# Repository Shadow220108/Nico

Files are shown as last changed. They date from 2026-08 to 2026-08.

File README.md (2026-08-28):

<h1 align="center">
  <br>
  Screenshot 2026-08-28 032631-Photoroom

  <br>
  Nico
  <br>
</h1>
<h3 align="center">
Ultra-compact USB dongle with a 56-LED Charlieplexed visualizer and native CH552 8051 control.
</h3>

| Spinnyy |
| --- |
|  |

| Front Render | Back Render | 
| --- | --- |
|| | 

## PCB Design 
| |
|--- |  

 ### The PCB is 2 layers with dimensions 76 by 21 mm

## Schematics  

Here are the schematic designs,

| |
| --- |  

## How can you get one for yourself? 

That is pretty easy, you have all the files you will need in the production folder, order the development  
board from any PCB fab ( I chose JLC cause its cheap and has good quality ) and BINGO! You will have it  
to use for any purpose you want!  

## BOM  
|Name|Purpose |Quantity|Total Cost (USD)|Link |Distributor|
|----|---|---|---|---|---|
|PCB |Development Board|5 |43.09 ( After coupons ) |https://jlcpcb.com/|JLCPCB |
|Components |all the components grouped together|1 | 28.75 |https://www.lcsc.com|LCSC |
| | | Total | 71.84 | 

LCSC BOM for the components on board is [here](https://github.com/Shadow220108/Nico/blob/main/production/bom.csv)

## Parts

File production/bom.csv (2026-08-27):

Designator | Footprint | Quantity | Value | LCSC Part #
220R, R3, R4, R5, R6, R7, R8, R9 | 0603 | 8 | 220R
BOOT | SW_SPST_TS-1088-xR020 | 1 | Boot
C1, C2 | 0603 | 2 | 100nF
D1, D10, D11, D12, D13, D14, D15, D16, D17, D18, D19, D2, D20, D21, D22, D23, D24, D25, D26, D27, D28, D29, D3, D30, D31, D32, D33, D34, D35, D36, D37, D38, D39, D4, D40, D41, D42, D43, D44, D45, D46, D47, D48, D49, D5, D50, D51, D52, D53, D54, D55, D56, D6, D7, D8, D9 | 0603 | 56 | RED
J1 | USB-A | 1 | USB_A
R1 | 0603 | 1 | 10k
U1 | SOIC-16_3.9x9.9mm_P1.27mm | 1 | CH552G | C111292

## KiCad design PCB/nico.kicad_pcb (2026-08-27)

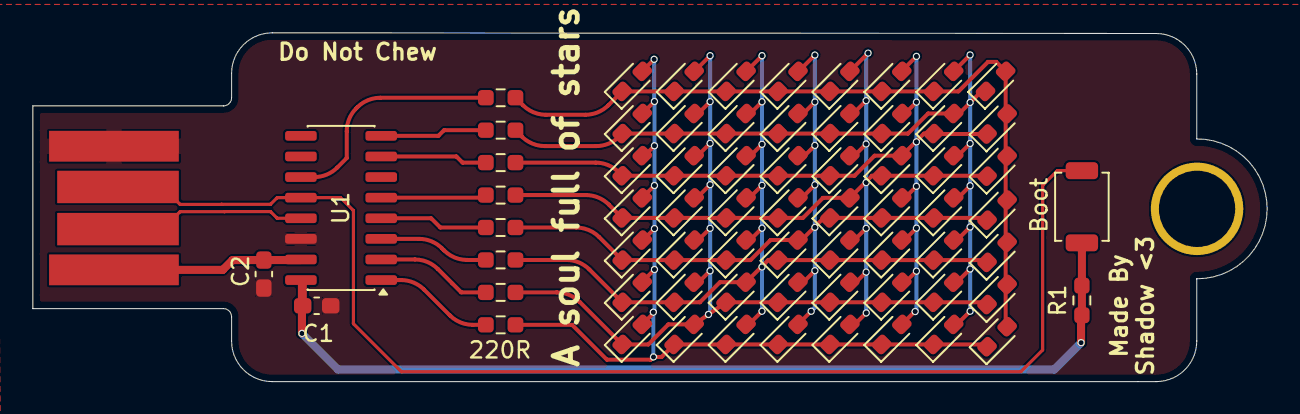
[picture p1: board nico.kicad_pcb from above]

Board: 2 copper layers, 76.1 x 21.5 mm, 70 parts (0 on the bottom side), 14 nets.

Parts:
220R: 220R; R_0603_1608Metric_Pad0.98x0.95mm_HandSolder
Boot: Boot; SW_SPST_TS-1088-xR020
C1, C2: 100nF; C_0603_1608Metric_Pad1.08x0.95mm_HandSolder
D1, D2, D3, D4, D5, D6, D7, D8, D9, D10, D11, D12, D13, D14, D15, D16, D17, D18, D19, D20, D21, D22, D23, D24, D25, D26, D27, D28, D29, D30, D31, D32, D33, D34, D35, D36, D37, D38, D39, D40, D41, D42, D43, D44, D45, D46, D47, D48, D49, D50, D51, D52, D53, D54, D55, D56: RED; LED_0603_1608Metric_Pad1.05x0.95mm_HandSolder
J1: USB_A; USB-A
R1: 10k; R_0603_1608Metric_Pad0.98x0.95mm_HandSolder
R3, R4, R5, R6, R7, R8, R9: 220R; R_0603_1608Metric_Pad0.98x0.95mm_HandSolder
U1: CH552G; SOIC-16_3.9x9.9mm_P1.27mm

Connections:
+3V3: C1.1, R1.1, U1.16 (V33)
/D+: Boot.1, J1.3 (D+), U1.12 (P3.6/UDP)
/D-: J1.2 (D-), U1.13 (P3.7/UDM)
/ROW0: 220R.1, 220R.2, D1.1 (K), D8.1 (K), D15.1 (K), D22.1 (K), D29.1 (K), D36.1 (K), D43.1 (K), D50.2 (A), D51.2 (A), D52.2 (A), D53.2 (A), D54.2 (A), D55.2 (A), D56.2 (A), U1.11 (P3.4/PWM2/RXD1_/T0)
/ROW1: D2.1 (K), D9.1 (K), D16.1 (K), D23.1 (K), D30.1 (K), D37.1 (K), D43.2 (A), D44.2 (A), D45.2 (A), D46.2 (A), D47.2 (A), D48.2 (A), D49.2 (A), D50.1 (K), R3.1, R3.2, U1.8 (P3.0/PWM1_/RXD)
/ROW2: D3.1 (K), D10.1 (K), D17.1 (K), D24.1 (K), D31.1 (K), D36.2 (A), D37.2 (A), D38.2 (A), D39.2 (A), D40.2 (A), D41.2 (A), D42.2 (A), D44.1 (K), D51.1 (K), R4.1, R4.2, U1.7 (P3.1/PWM2_/TXD)
/ROW3: D4.1 (K), D11.1 (K), D18.1 (K), D25.1 (K), D29.2 (A), D30.2 (A), D31.2 (A), D32.2 (A), D33.2 (A), D34.2 (A), D35.2 (A), D38.1 (K), D45.1 (K), D52.1 (K), R5.1, R5.2, U1.5 (P1.7/SCK/TXD1/TIN5)
/ROW4: D5.1 (K), D12.1 (K), D19.1 (K), D22.2 (A), D23.2 (A), D24.2 (A), D25.2 (A), D26.2 (A), D27.2 (A), D28.2 (A), D32.1 (K), D39.1 (K), D46.1 (K), D53.1 (K), R6.1, R6.2, U1.4 (P1.6/MISO/RXD1/TIN4)
/ROW5: D6.1 (K), D13.1 (K), D15.2 (A), D16.2 (A), D17.2 (A), D18.2 (A), D19.2 (A), D20.2 (A), D21.2 (A), D26.1 (K), D33.1 (K), D40.1 (K), D47.1 (K), D54.1 (K), R7.1, R7.2, U1.3 (P1.5/MOSI/PWM1/TIN3/UCC2/AIN2)
/ROW6: D7.1 (K), D8.2 (A), D9.2 (A), D10.2 (A), D11.2 (A), D12.2 (A), D13.2 (A), D14.2 (A), D20.1 (K), D27.1 (K), D34.1 (K), D41.1 (K), D48.1 (K), D55.1 (K), R8.1, R8.2, U1.2 (P1.4/T2_/CAP1_/SCS/TIN2/UCC1/AIN1)
/ROW7: D1.2 (A), D2.2 (A), D3.2 (A), D4.2 (A), D5.2 (A), D6.2 (A), D7.2 (A), D14.1 (K), D21.1 (K), D28.1 (K), D35.1 (K), D42.1 (K), D49.1 (K), D56.1 (K), R9.1, R9.2, U1.1 (P3.2/TXD1_/INT0/VBUS1/AIN3)
GND: C1.2, C2.2, J1.4 (GND), U1.14 (GND/VSS)
unnamed: Boot.2, R1.2
VBUS: C2.1, J1.1 (VBUS), U1.15 (VCC/VDD)

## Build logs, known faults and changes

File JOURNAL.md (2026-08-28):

## Nico

Ultra-compact USB dongle with a 56-LED Charlieplexed visualizer and native CH552 8051 control.

## Total Hours : 14.4 hours

#### August 27, 2:33 am 
 Time Spent : 1.8 hours  
Starting with the #dongle ysws, I found this pretty cool ysws to make my own dongle! On top of it, it is run by @Sophia ( fallout was so fun cause of her ), okay so now I need an idea, after scrolling through internet and braingstorming I came up with designing an LED matrix, using the CH32V003 chip 
One of the inspo I found : 
Five Boards

After talking with @Sophia on channel I found out that I should switch to a chip that supports native USB support, so I had to switch to a different chip ( CH552G ) and have a led matrix using that

---

#### August 27, 4:22 am

Time Spent : 1.6 hours  
I started by importing the CH552G symbol and footprint from lcsc using the easyeda2kicad library, looked up at the CH552G datasheet then got shocked that it was in Chinese and had to use a translator! I found out this very amazing [blog](https://stkwans.blogspot.com/2012/05/designing-large-charlieplex.html) on internet explaining the charlieplexxed matrixes I used that to design my matrix and connected everything in the schematics! 


---

#### August 27, 10:01 pm
Time Spent : 2.2 hours  
In this journal, I placed the footprints for the components, I am using 0603 footprints making it easy to hand solder and still be compact! This is how it looked after importing the components 
  

then I started arranging everything, my first approach was to arrange everything manually, took a lot of time wasnt accurate 2/10, next method which I found was creating an array, it arranged the leds on what i wanted but randomly rather than in sequence, 5/10, after that my only hope was to arange them using precise move tool which worked fast, was accurate and yippee  


--- 

#### August 28, 2:31 am 
Time spent : 3.8 hours  
After talking with sophia, I decided to rotate the LEDs by 45 degrees to make it look dope! then started routing everything, it was my first time routing a charlieplexxed matrix so it was tricky but I got all the horizontal traces on top layer and vertical ones on bottom, making it easier! 
  

  

--- 

### August 28, 6:30 am
Time spent : 3 hours  
After I finished routing, sophia told to bring the LEDs closer, now I agreed with her, thats why had to change the shape, bring my leds closer and route everything again! It was easier this time and took a lot less time! I also decided to add a keyring to it! makes it look cool

After that I got some art from pinterest for my board! and since i am getting ENIG having it etched on solder mask makes it look pretty cool 


Perfect to ship it now!

---
## August 29, 1:30 am

Time Spent : 2 hours   

Last but not the least, this is my final journal, uploading all the files to github, writing the readme and most importantly getting the BOM, the price of this dongle went crazy already in 100s but with coupons and hand soldering I brought it down to 74! ( Sorry Sophia for expensive PCB but its so cool ) 

---

#### If you are reading by here, thanks! I hope this inspires you to make one of your own! Special credits to Sophia ( I swear I have said Sophia so many times in my journal ) and HackClub!

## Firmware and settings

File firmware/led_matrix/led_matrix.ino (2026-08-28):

#include <ch554.h>

void delay_us(uint16_t us) {
    while (us--) {
        __asm__("nop\n\tnop\n\tnop\n\tnop\n\tnop\n\t");
    }
}

void delay_ms(uint16_t ms) {
    while (ms--) {
        delay_us(1000);
    }
}

void reset_all_pins(void) {
    P1_MOD_OC &= ~((1<<4) | (1<<5) | (1<<6) | (1<<7));
    P1_DIR_PU &= ~((1<<4) | (1<<5) | (1<<6) | (1<<7));

    P3_MOD_OC &= ~((1<<0) | (1<<1) | (1<<2) | (1<<4));
    P3_DIR_PU &= ~((1<<0) | (1<<1) | (1<<2) | (1<<4));
}

void set_pin(uint8_t pin_idx, uint8_t level) {
    switch(pin_idx) {
        case 0: 
            P3_DIR_PU |= (1<<4);
            P3_MOD_OC &= ~(1<<4);
            if(level) P3 |= (1<<4); else P3 &= ~(1<<4);
            break;
        case 1: 
            P3_DIR_PU |= (1<<2);
            P3_MOD_OC &= ~(1<<2);
            if(level) P3 |= (1<<2); else P3 &= ~(1<<2);
            break;
        case 2:
            P1_DIR_PU |= (1<<4);
            P1_MOD_OC &= ~(1<<4);
            if(level) P1 |= (1<<4); else P1 &= ~(1<<4);
            break;
        case 3: 
            P1_DIR_PU |= (1<<5);
            P1_MOD_OC &= ~(1<<5);
            if(level) P1 |= (1<<5); else P1 &= ~(1<<5);
            break;
        case 4: 
            P1_DIR_PU |= (1<<6);
            P1_MOD_OC &= ~(1<<6);
            if(level) P1 |= (1<<6); else P1 &= ~(1<<6);
            break;
        case 5:
            P1_DIR_PU |= (1<<7);
            P1_MOD_OC &= ~(1<<7);
            if(level) P1 |= (1<<7); else P1 &= ~(1<<7);
            break;
        case 6: 
            P3_DIR_PU |= (1<<1);
            P3_MOD_OC &= ~(1<<1);
            if(level) P3 |= (1<<1); else P3 &= ~(1<<1);
            break;
        case 7: 
            P3_DIR_PU |= (1<<0);
            P3_MOD_OC &= ~(1<<0);
            if(level) P3 |= (1<<0); else P3 &= ~(1<<0);
            break;
    }
}

// ASCII Art Bitmaps (8 rows x 7 columns)
// Bit 0 corresponds to Column 0 (ROW7), Bit 6 corresponds to Column 6 (ROW0)
__code const uint8_t HEART_FRAME[8] = {
    0b01100110, //  . * * . . * * .
    0b11111111, //  * * * * * * * *
    0b11111111, //  * * * * * * * *
    0b11111111, //  * * * * * * * *
    0b01111110, //  . * * * * * * .
    0b00111100, //  . . * * * * . .
    0b00011000, //  . . . * * . . .
    0b00000000  //  . . . . . . . .
};

__code const uint8_t SMILEY_FRAME[8] = {
    0b00111100, //  . . * * * * . .
    0b01000010, //  . * . . . . * .
    0b10100101, //  * . * . . * . *
    0b10000001, //  * . . . . . . *
    0b10100101, //  * . * . . * . *
    0b10011001, //  * . . * * . . *
    0b01000010, //  . * . . . . * .
    0b00111100  //  . . * * * * . .
};

// Charlieplex scanning function: scans 1 frame over a set duration
void display_bitmap(const uint8_t *bitmap, uint16_t duration_ms) {
    uint16_t cycles = duration_ms; // each full 8-row cycle takes ~800us (~1ms)
    
    while(cycles--) {
        for (uint8_t row = 0; row < 8; row++) {
            uint8_t row_data = bitmap[row];
            
            // Activate the row by driving it HIGH
            for (uint8_t col = 0; col < 8; col++) {
                if (row == col) continue; // Cannot drive self in Charlieplexing
                
                // If the bit for this LED is 1, light it by sinking the column pin
                if (row_data & (1 << (col > row ? col - 1 : col))) {
                    reset_all_pins();
                    set_pin(row, 1); // Anode (VCC)
                    set_pin(col, 0); // Cathode (GND)
                    delay_us(100);   // Persistence pulse
                }
            }
        }
    }
    reset_all_pins();
}

void main(void) {
    // Set internal clock
    SAFE_MOD = 0x55;
    SAFE_MOD = 0xAA;
    CLOCK_CFG = CLOCK_CFG & ~MASK_SYS_CK_DIV | 0x06; // Standard 24MHz internal clock
    
    reset_all_pins();

    while (1) {
        display_bitmap(HEART_FRAME, 1000);  // Show Heart for 1 second
        display_bitmap(SMILEY_FRAME, 1000); // Show Smiley for 1 second
    }
}
